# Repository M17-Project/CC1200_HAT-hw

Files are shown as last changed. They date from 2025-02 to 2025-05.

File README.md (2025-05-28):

## CC1200_HAT-hw 
CC1200 RF Raspberry Pi Zero shield.

### Board overview
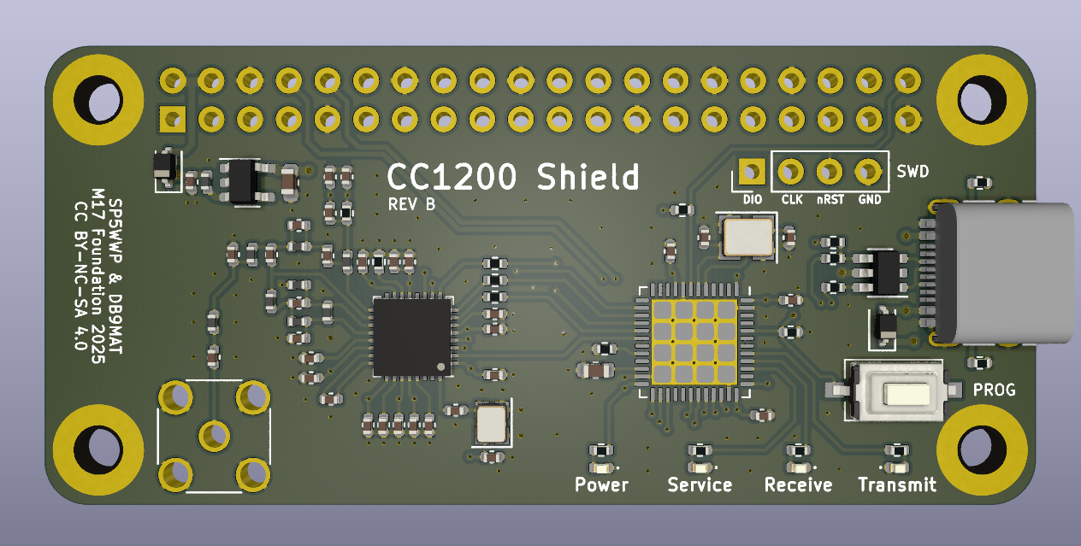
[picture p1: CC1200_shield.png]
PCB top view


### Programming
See the [firmware's GitHub repository](https://github.com/M17-Project/CC1200_HAT-fw?tab=readme-ov-file#flashing)
for details.

### 40MHz TCXO
In case the `FT2MNTUM-40.0-T1` 40MHz crystal oscillator (X1) is not available, a valid replacement for it is `TG2520SMN 40.0000M-MCGNNM0`.

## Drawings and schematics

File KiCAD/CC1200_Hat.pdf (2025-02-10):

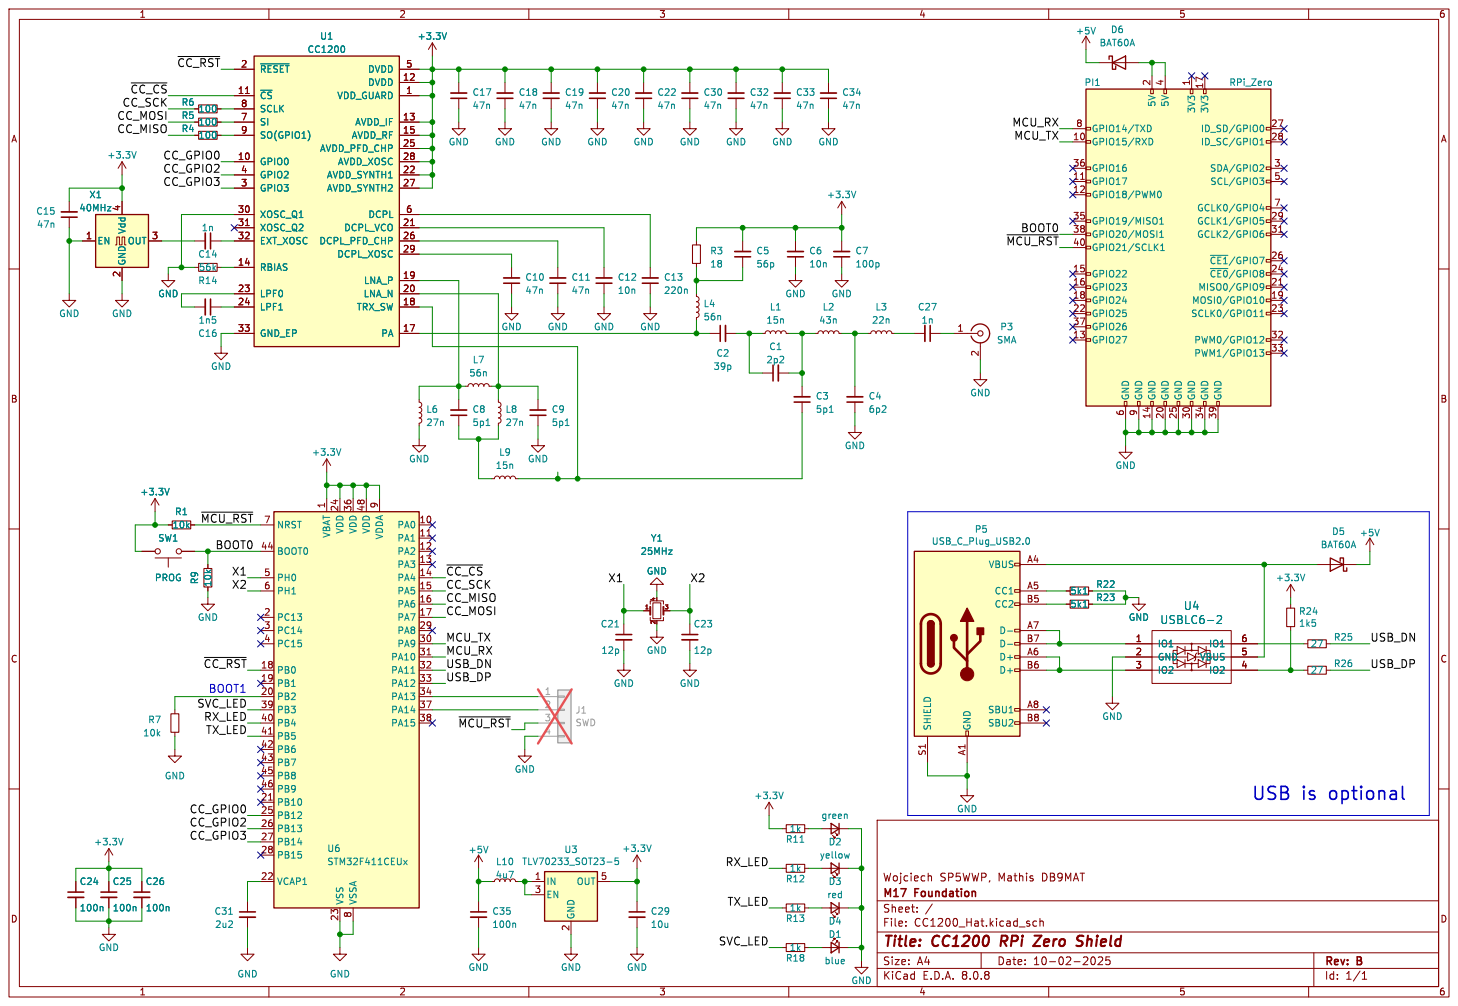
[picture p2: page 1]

2 EN 3 OUT 5 U3 TLV70233_SOT23-5 R22 5k1 R23 5k1 GNDGND GND

1 PA0 10 PA1 11 PA2 12 PA3 13 PA4 14 PA5 15 PA6 16 PA7 17 PB0 18 PB1 19 PC13 2 PB2 20 PB10 21 VCAP1 22 VSS 23 VDD 24 PB12 25 PB13 26 PB14 27 PB15 28 PA8 29 PC14 3 PA9 30 PA10 31 PA11 32 PA12 33 PA13 34 VDD 36 PA14 37 PA15 38 PB3 39 PC15 4 PB4 40 PB5 41 PB6 42 PB7 43 BOOT0 44 PB8 45 PB9 46 VDD 48 PH0 5 PH1 6 NRST 7 VSSA

Id: 1/1 Title: CC1200 RPi Zero Shield

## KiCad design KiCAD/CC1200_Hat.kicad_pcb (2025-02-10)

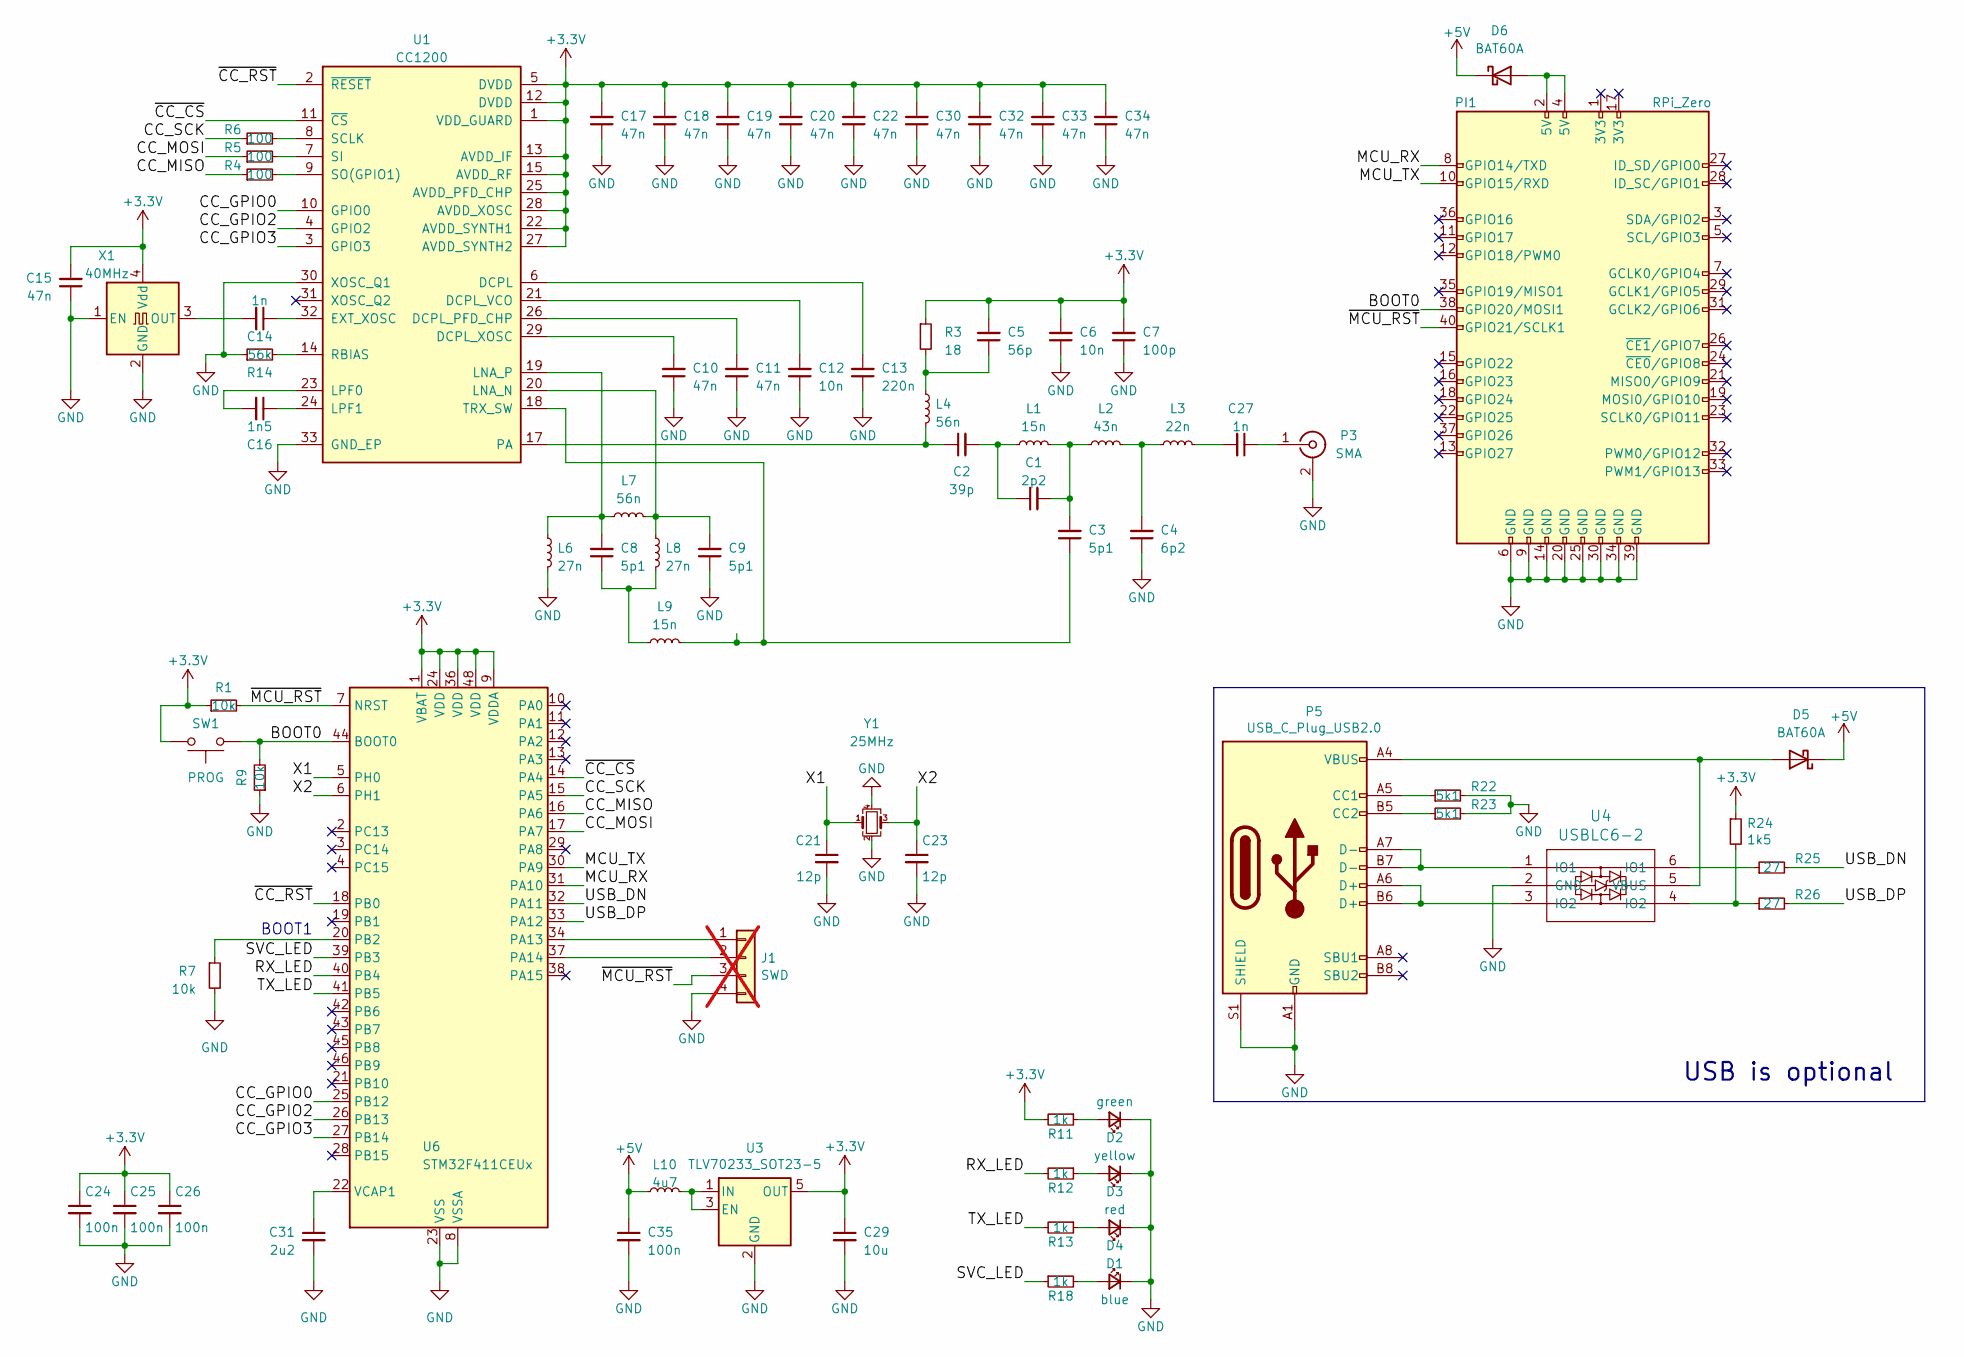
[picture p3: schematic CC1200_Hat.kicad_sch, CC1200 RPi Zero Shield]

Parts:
C1: 2p2; C_0402_1005Metric; MPN GCM1555C1H2R2BA16J
C2: 39p; C_0402_1005Metric; MPN GRM1555C2A390JA1D
C3, C8, C9: 5p1; C_0402_1005Metric; MPN GJM1555C1H5R1DB1D
C4: 6p2; C_0402_1005Metric; MPN GCM1555C1H6R2BA6D
C5: 56p; C_0402_1005Metric; MPN 04025A560JAT4A
C6, C12: 10n; C_0402_1005Metric; MPN 0402B103K6R3CT
C7: 100p; C_0402_1005Metric; MPN CL05C101JB5NNNC
C10, C11, C15, C17, C18, C19, C20, C22, C30, C32, C33, C34: 47n; C_0402_1005Metric; MPN GCM155L8EH473KE7D
C13: 220n; C_0402_1005Metric; MPN CGA2B3X5R1A224M050BB
C14, C27: 1n; C_0402_1005Metric; MPN GRT1555C1E102JA2J
C16: 1n5; C_0402_1005Metric; MPN 885012205026
C21, C23: 12p; C_0402_1005Metric; MPN C0402C120J5GACTU
C24, C25, C26, C35: 100n; C_0402_1005Metric; MPN VJ0402V104ZXJCW1BC
C29: 10u; C_0603_1608Metric; MPN CL10A106KQ8NNNC
C31: 2u2; C_0603_1608Metric; MPN CL10A225KO8NNWC
D1: blue; LED_0402_1005Metric; MPN APHHS1005QBC/D
D2: green; LED_0402_1005Metric; MPN APHHS1005CGCK
D3: yellow; LED_0402_1005Metric; MPN APG1005SYC-T
D4: red; LED_0402_1005Metric; MPN APHHS1005SURCK
D5, D6: BAT60A; D_SOD-323; MPN BAT60AE6327XT
J1: SWD; PinHeader_1x04_P2.54mm_Vertical; not fitted
L1, L9: 15n; L_0402_1005Metric; MPN LQG15HZ15NJ02D
L2: 43n; L_0402_1005Metric; MPN LQG15WZ43NJ02D
L3: 22n; L_0402_1005Metric; MPN LQG15HZ22NH02D
L4, L7: 56n; L_0402_1005Metric; MPN LCCI0402J56NGTAR
L6, L8: 27n; L_0402_1005Metric; MPN LQG15HN27NJ02D
L10: 4u7; L_0402_1005Metric; MPN PLEA67BCA4R7M-1PT00
P3: SMA; SMA_Wurth_60312002114503_Vertical; MPN RF2-04A-T-00-50-G
P5: USB_C_Plug_USB2.0; USB_C_Receptacle_HRO_TYPE-C-31-M-12; MPN TYPE-C-31-M-12
PI1: RPi_Zero; Raspberry_Pi_Zero_Socketed_THT_FaceDown_MountingHoles
R1, R7, R9: 10k; R_0402_1005Metric; MPN RC0402JR-1010KL
R3: 18; R_0402_1005Metric; MPN ERJ-2GEJ180X
R4, R5, R6: 100; R_0402_1005Metric; MPN CR0402AJW-101GLF
R11, R12, R13, R18: 1k; R_0402_1005Metric; MPN ERJ-PA2D1001X
R14: 56k; R_0402_1005Metric; MPN RK73B1ETTP563J
R22, R23: 5k1; R_0402_1005Metric; MPN RC0402FR-075K1L
R24: 1k5; R_0402_1005Metric; MPN AC0402JR-7W1K5L
R25, R26: 27; R_0402_1005Metric; MPN CRCW040210K0FKED
SW1: PROG; SW_Tactile_SPST_NO_Straight_CK_PTS636Sx25SMTRLFS; MPN PTS636SM43JSMTR LFS
U1: CC1200; QFN-32-1EP_5x5mm_P0.5mm_EP3.45x3.45mm; MPN CC1200RHBR
U3: TLV70233_SOT23-5; SOT-23-5; MPN TLV70233PDBVR
U4: USBLC6-2; SOT-23-6; MPN USBLC6-2SC6
U6: STM32F411CEUx; QFN-48-1EP_7x7mm_P0.5mm_EP5.6x5.6mm; MPN STM32F411CEU6
X1: 40MHz; Oscillator_SMD_SeikoEpson_SG210-4Pin_2.5x2.0mm; MPN FT2MNTUM-40.0-T1
Y1: 25MHz; Crystal_SMD_3225-4Pin_3.2x2.5mm; MPN EB2532YA08-25.000M TR

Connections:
+3.3V: C5.2, C6.2, C7.2, C15.2, C17.2, C18.2, C19.2, C20.2, C22.2, C24.1, C25.1, C26.1, C29.1, C30.2, C32.2, C33.2, C34.2, R1.1, R3.1, R11.2, R24.1, SW1.2, U1.1 (VDD_GUARD), U1.5 (DVDD), U1.12 (DVDD), U1.13 (AVDD_IF), U1.15 (AVDD_RF), U1.22 (AVDD_SYNTH1), U1.25 (AVDD_PFD_CHP), U1.27 (AVDD_SYNTH2), U1.28 (AVDD_XOSC), U3.5 (OUT), U6.1 (VBAT), U6.9 (VDDA), U6.24 (VDD), U6.36 (VDD), U6.48 (VDD), X1.4 (Vdd)
+5V: C35.1, D5.1 (K), D6.1 (K), L10.1
/BOOT0: PI1.38 (GPIO20/MOSI1), R9.2, SW1.1, U6.44 (BOOT0)
/CC_GPIO0: U1.10 (GPIO0), U6.25 (PB12)
/CC_GPIO2: U1.4 (GPIO2), U6.26 (PB13)
/CC_GPIO3: U1.3 (GPIO3), U6.27 (PB14)
/CC_MISO: R4.1, U6.16 (PA6)
/CC_MOSI: R5.1, U6.17 (PA7)
/CC_SCK: R6.1, U6.15 (PA5)
/MCU_RX: PI1.8 (GPIO14/TXD), U6.31 (PA10)
/MCU_TX: PI1.10 (GPIO15/RXD), U6.30 (PA9)
/RX_LED: R12.2, U6.40 (PB4)
/SVC_LED: R18.1, U6.39 (PB3)
/TX_LED: R13.2, U6.41 (PB5)
/USB_DN: R25.2, U6.32 (PA11)
/USB_DP: R26.2, U6.33 (PA12)
/X1: C21.1, U6.5 (PH0), Y1.1
/X2: C23.1, U6.6 (PH1), Y1.3
/~CC_CS: U1.11 (~CS), U6.14 (PA4)
/~CC_RST: U1.2 (~RESET), U6.18 (PB0)
/~MCU_RST: J1.3, PI1.40 (GPIO21/SCLK1), R1.2, U6.7 (NRST)
GND: C4.1, C6.1, C7.1, C9.1, C10.1, C11.1, C12.1, C13.1, C15.1, C17.1, C18.1, C19.1, C20.1, C21.2, C22.1, C23.2, C24.2, C25.2, C26.2, C29.2, C30.1, C31.2, C32.1, C33.1, C34.1, C35.2, D1.1 (K), D2.1 (K), D3.1 (K), D4.1 (K), J1.4, L6.2, P3.2 (Ext), P5.A1 (GND), P5.A12 (GND), P5.B1 (GND), P5.B12 (GND), P5.S1 (SHIELD), PI1.6 (GND), PI1.9 (GND), PI1.14 (GND), PI1.20 (GND), PI1.25 (GND), PI1.30 (GND), PI1.34 (GND), PI1.39 (GND), R7.2, R9.1, R14.1, R22.2, R23.2, U1.30 (XOSC_Q1), U1.33 (GND_EP), U3.2 (GND), U4.2 (GND), U6.8 (VSSA), U6.23 (VSS), U6.35 (VSS), U6.47 (VSS), U6.49 (VSS), X1.1 (EN), X1.2 (GND), Y1.2, Y1.4
unnamed: C1.1, C2.2, L1.1
unnamed: C1.2, C3.2, L1.2, L2.1
unnamed: C4.2, L2.2, L3.1
unnamed: C5.1, L4.1, R3.2
unnamed: C8.1, L8.2, L9.1
unnamed: C27.2, L3.2
unnamed: D1.2 (A), R18.2
unnamed: D2.2 (A), R11.1
unnamed: D3.2 (A), R12.1
unnamed: D4.2 (A), R13.1
unnamed: D5.2 (A), P5.A4 (VBUS), P5.A9 (VBUS), P5.B4 (VBUS), P5.B9 (VBUS), U4.5 (VBUS)
unnamed: D6.2 (A), PI1.2 (5V), PI1.4 (5V)
unnamed: J1.1, U6.34 (PA13)
unnamed: J1.2, U6.37 (PA14)
unnamed: C27.1, P3.1 (In)
unnamed: P5.A5 (CC1), R22.1
unnamed: P5.B5 (CC2), R23.1
unnamed: P5.A6 (D+), P5.B6 (D+), U4.3 (IO2)
unnamed: P5.A7 (D-), P5.B7 (D-), U4.1 (IO1)
unnamed: R24.2, R26.1, U4.4 (IO2)
unnamed: R25.1, U4.6 (IO1)
unnamed: C13.2, U1.6 (DCPL)
unnamed: C11.2, U1.26 (DCPL_PFD_CHP)
unnamed: C12.2, U1.21 (DCPL_VCO)
unnamed: C10.2, U1.29 (DCPL_XOSC)
unnamed: C14.1, U1.32 (EXT_XOSC)
unnamed: C9.2, L7.2, L8.1, U1.20 (LNA_N)
unnamed: C8.2, L6.1, L7.1, U1.19 (LNA_P)
unnamed: C16.2, U1.23 (LPF0)
unnamed: C16.1, U1.24 (LPF1)
unnamed: C2.1, L4.2, U1.17 (PA)
unnamed: R14.2, U1.14 (RBIAS)
unnamed: R6.2, U1.8 (SCLK)
unnamed: R5.2, U1.7 (SI)
unnamed: R4.2, U1.9 (SO(GPIO1))
unnamed: C3.1, L9.2, U1.18 (TRX_SW)
unnamed: L10.2, U3.1 (IN), U3.3 (EN)
unnamed: R7.1, U6.20 (PB2)
unnamed: C31.1, U6.22 (VCAP1)
unnamed: C14.2, X1.3 (OUT)

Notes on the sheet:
BOOT1
USB is optional

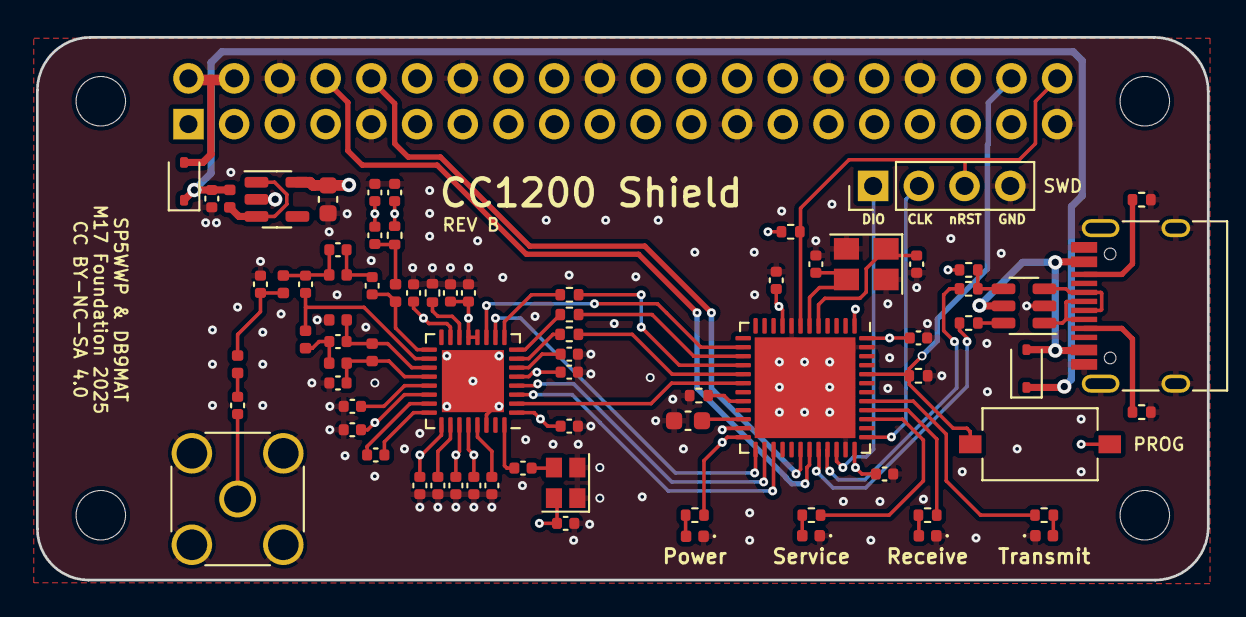
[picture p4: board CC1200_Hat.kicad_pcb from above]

Board: 4 copper layers, 65.1 x 30.2 mm, 77 parts (1 on the bottom side), 62 nets.

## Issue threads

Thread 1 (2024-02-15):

OLED pin header - P1

sp5wwp, 2024-02-15:
Move it closer to the board's edge.

sp5wwp, 2025-02-06:
Having a display is not required at this time. Closing for now.

Closed 2025-02-06.

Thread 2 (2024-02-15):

TRX GPIO pin routing

sp5wwp, 2024-02-15:
All three CC1200 GPIOs are routed to MCU pins sharing the same interrupt group - `EXTI15_10_IRQn`.

Solution: wouldn't it be wise to re-route two of them to other pins so IRQs can be masked?

sp5wwp, 2024-10-11:
It's not a problem.

Closed 2024-10-11.

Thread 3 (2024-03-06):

XOSC_Q1 pin left floating

sp5wwp, 2024-03-06:
Connect the `XOSC_Q1` pin of CC1200 to GND, as per datasheet, page 6:
`Crystal oscillator pin 1 (must be grounded if a TCXO or other external clock connected to EXT_XOSC is used)`

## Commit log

2025-02-06 cleanup/update
    - schematic/pcb cleanup
    - WIP PN assignment
    - KiCAD version update
    [CC1200_Hat.kicad_pcb, CC1200_Hat.kicad_sch]
2025-02-07 minor updates
    - pcb update - "PROG" button
    - readme update
    - WIP PN update
    [CC1200_Hat.kicad_pcb, CC1200_Hat.kicad_sch]
2025-02-07 PN assignment
    [CC1200_Hat.kicad_pcb, CC1200_Hat.kicad_sch]
2025-02-10 MPN fixes for Mouser
    [CC1200_Hat.kicad_pcb, CC1200_Hat.kicad_sch]
2025-03-10 updates
    - KiCAD version bump to 9.0
    - BOM value update for R25 & R26
    [CC1200_Hat.kicad_sch]

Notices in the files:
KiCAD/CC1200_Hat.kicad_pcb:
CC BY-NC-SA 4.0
